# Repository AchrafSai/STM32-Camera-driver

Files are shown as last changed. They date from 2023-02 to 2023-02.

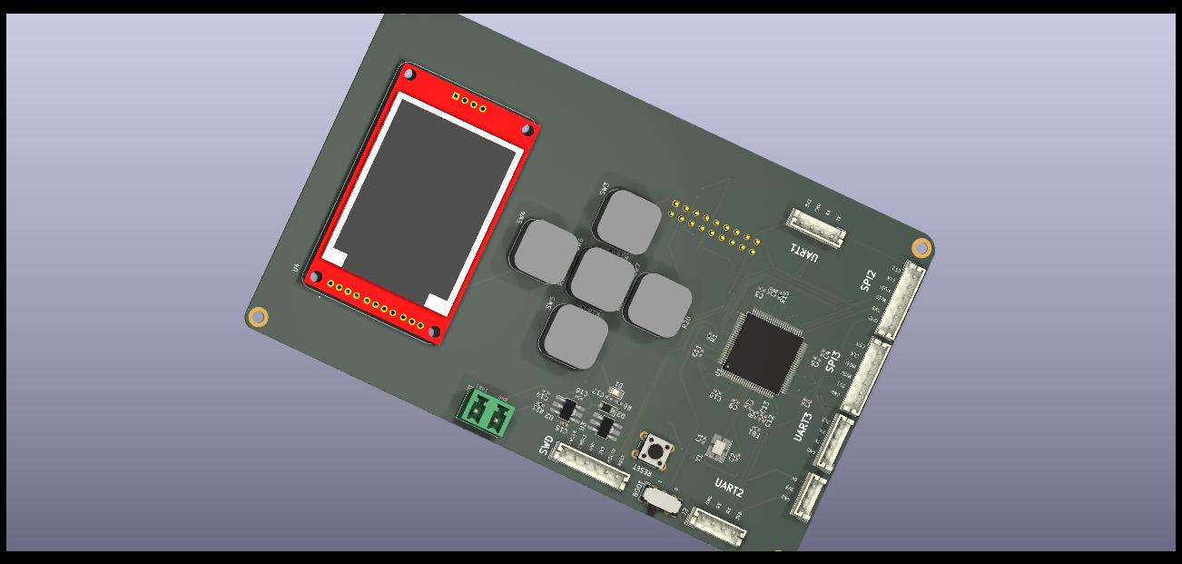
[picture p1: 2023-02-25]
STM32 Camera driver 1.jpg

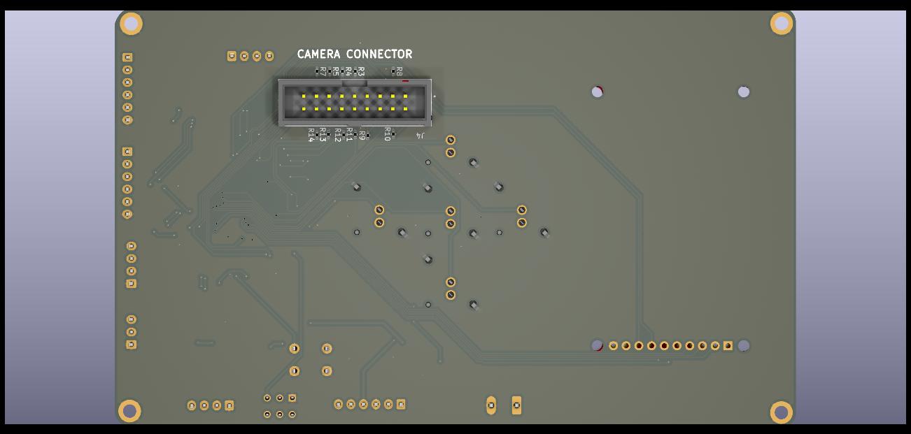
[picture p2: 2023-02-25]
STM32 Camera driver back.jpg

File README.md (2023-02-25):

# STM32 Camera Driver PCB

This project is a custom-designed Printed Circuit Board (PCB) that integrates an STM32H7 microcontroller, a camera module, a display, five buttons, and multiple communication ports.

## Features
The key features of this project are:

STM32H7 Microcontroller: The STM32H7 is a powerful 32-bit microcontroller with a dual-core ARM Cortex-M7 and Cortex-M4 processor, capable of running at up to 480 MHz. It offers a wide range of peripherals and connectivity options, making it ideal for embedded systems applications.

Camera Module: The camera module used in this project is a high-resolution OV5640 sensor that captures 5-megapixel still images and 720p video at 60 frames per second.

Display: The display used in this project is a 1.8-inch TFT LCD screen with a resolution of 320x240 pixels. It provides a clear and bright display for viewing images and video captured by the camera.

Five Buttons: The board includes five buttons for user input, allowing users to control the camera and interact with the user interface displayed on the screen.

Communication Ports: The board includes multiple communication ports, including USB, UART, SPI, and I2C, providing flexibility for communicating with other devices and systems.

## Repository Contents
This repository contains the design files for the PCB, including the schematic, PCB layout, and bill of materials. The KiCad project files are provided, as well as PDFs of the schematic and PCB layout for easy viewing.

## Getting Started
To use this PCB, you will need to assemble and program it. The bill of materials provides a list of components needed, and the KiCad project files can be used to generate the Gerber files needed to manufacture the PCB.

Once the PCB is assembled, you can use the provided example code to get started. The code includes basic functionality for capturing images and video, displaying them on the screen, and interacting with the user through the buttons.

## License
This project is released under the MIT License, meaning that you are free to use, modify, and distribute the code and design files for both personal and commercial use. However, please note that the camera module used in this project may be subject to additional licensing restrictions.

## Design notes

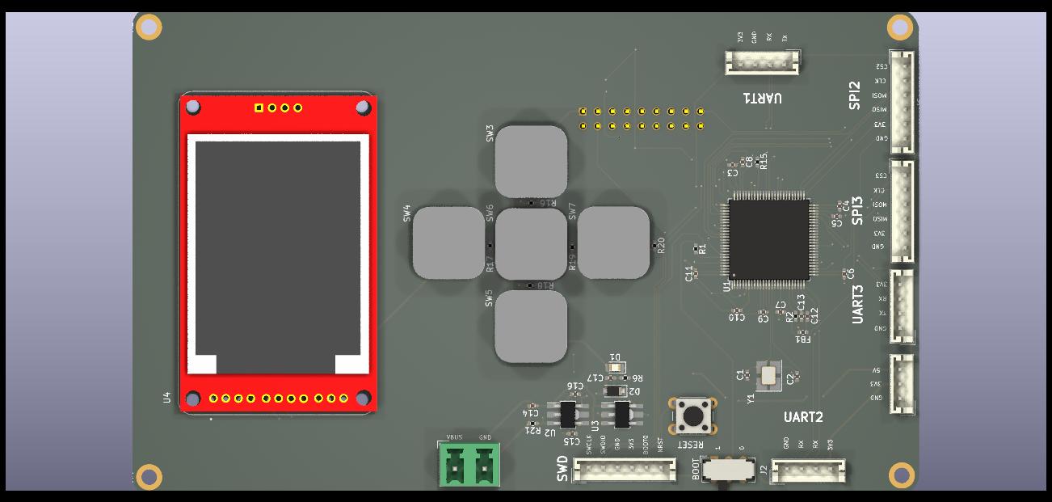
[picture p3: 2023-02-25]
STM32 Camera driver.jpg

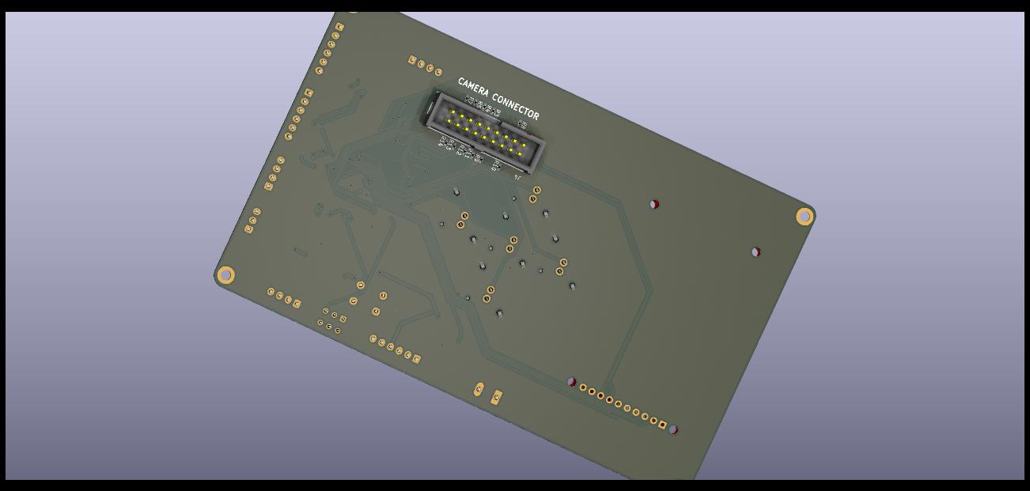
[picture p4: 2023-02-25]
STM32 Camera driver back 1.jpg

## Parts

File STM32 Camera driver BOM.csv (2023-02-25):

Source: | /home/achraf/Documents/KiCad/STM32 Camera driver/STM32 Camera driver.kicad_sch
Date: | 02,15,2023
Tool: | Eeschema 6.0.10-86aedd382b~118~ubuntu20.04.1
Generator: | /usr/share/kicad/plugins/bom_csv_grouped_by_value_with_fp.py
Component Count: | 66
Ref | Qnty | Value | Cmp name | Footprint | Description | Vendor
C1, C2, | 2 | 18p | C | Capacitor_SMD:C_0402_1005Metric_Pad0.74x0.62mm_HandSolder | Unpolarized capacitor
C3, C4, C6, C7, C9, C10, C11, C12, | 8 | 100n | C | Capacitor_SMD:C_0402_1005Metric_Pad0.74x0.62mm_HandSolder | Unpolarized capacitor
C5, C8, | 2 | 2.2u | C | Capacitor_SMD:C_0402_1005Metric_Pad0.74x0.62mm_HandSolder | Unpolarized capacitor
C13, | 1 | 1u | C | Capacitor_SMD:C_0402_1005Metric_Pad0.74x0.62mm_HandSolder | Unpolarized capacitor
C14, C15, C16, C17, | 4 | 3.3u | C | Capacitor_SMD:C_0402_1005Metric_Pad0.74x0.62mm_HandSolder | Unpolarized capacitor
D1, | 1 | LED | LED | LED_SMD:LED_0805_2012Metric_Pad1.15x1.40mm_HandSolder | Light emitting diode
D2, | 1 | DIODE | DIODE | Diode_SMD:D_SOD-123F |  | https://www.lcsc.com/product-detail/Switching-span-style-background-color-ff0-Diode-span_Shanghai-Prisemi-Elec-PSBD1DF40V1H_C110730.html
FB1, | 1 | 600Ω@100MHz | FerriteBead | Inductor_SMD:L_0402_1005Metric_Pad0.77x0.64mm_HandSolder | Ferrite bead | https://www.lcsc.com/product-detail/Ferrite-Beads_Murata-Electronics-BLM15AG601SN1D_C76884.html
H1, H2, H3, H4, | 4 | MountingHole_Pad | MountingHole_Pad | MountingHole:MountingHole_2.7mm_M2.5_ISO14580_Pad | Mounting Hole with connection
J2, J3, | 2 | UART connector | Conn_01x04_Male | Connector_JST:JST_EH_B4B-EH-A_1x04_P2.50mm_Vertical | Generic connector, single row, 01x04, script generated (kicad-library-utils/schlib/autogen/connector/)
J4, | 1 | TST-109-01-G-D | TST-109-01-G-D | Library:SAMTEC_TST-109-01-G-D
J5, | 1 | Conn_01x03_Male | Conn_01x03_Male | Connector_JST:JST_EH_B3B-EH-A_1x03_P2.50mm_Vertical | Generic connector, single row, 01x03, script generated (kicad-library-utils/schlib/autogen/connector/)
J6, J9, J10, | 3 | Conn_01x06_Male | Conn_01x06_Male | Connector_JST:JST_EH_B6B-EH-A_1x06_P2.50mm_Vertical | Generic connector, single row, 01x06, script generated (kicad-library-utils/schlib/autogen/connector/)
J7, | 1 | Voltage input max 10V | Conn_01x02_Male | Connector_Phoenix_MC_HighVoltage:PhoenixContact_MCV_1,5_2-G-5.08_1x02_P5.08mm_Vertical | Generic connector, single row, 01x02, script generated (kicad-library-utils/schlib/autogen/connector/)
J11, | 1 | UART communication for camera | Conn_01x04_Male | Connector_JST:JST_EH_B4B-EH-A_1x04_P2.50mm_Vertical | Generic connector, single row, 01x04, script generated (kicad-library-utils/schlib/autogen/connector/)
R1, R8, R10, R16, R17, R18, R19, R20, R21, | 9 | 10k | R | Resistor_SMD:R_0402_1005Metric_Pad0.72x0.64mm_HandSolder | Resistor
R2, | 1 | 47R | R | Resistor_SMD:R_0402_1005Metric_Pad0.72x0.64mm_HandSolder | Resistor
R3, R4, R5, R7, R11, R12, R13, R14, | 8 | 22R | R_Small | Resistor_SMD:R_0402_1005Metric_Pad0.72x0.64mm_HandSolder | Resistor, small symbol
R6, | 1 | 1.5k | R | Resistor_SMD:R_0402_1005Metric_Pad0.72x0.64mm_HandSolder | Resistor
R9, R15, | 2 | 47k | R | Resistor_SMD:R_0402_1005Metric_Pad0.72x0.64mm_HandSolder | Resistor
SW1, | 1 | SW_DPDT_x2 | SW_DPDT_x2 | Button_Switch_THT:SW_CuK_JS202011AQN_DPDT_Angled | Switch, dual pole double throw, separate symbols
SW2, | 1 | SW_Push | SW_Push | Button_Switch_THT:SW_PUSH_6mm | Push button switch, generic, two pins
SW3, SW4, SW5, SW6, SW7, | 5 | SW_Push | SW_Push | Library:SW_PB300STQ_copy | Push button switch, generic, two pins | https://www.e-switch.com/product-catalog/pb300-series-long-travel-pushbutton-switch
U1, | 1 | STM32H743VITx | STM32H743VITx | Package_QFP:LQFP-100_14x14mm_P0.5mm | ARM Cortex-M7 MCU, 2048KB flash, 864KB RAM, 400MHz, 1.7-3.6V, 82 GPIO, LQFP-100
U2, | 1 | S-1133B50-U5T1x | S-1133_Series_1 | Library:SOT-89-5_Handsoldering
U3, | 1 | S-1133B33-U5T1x | S-1133_Series_1 | Library:SOT-89-5_Handsoldering
U4, | 1 | 358 | 358 | Library:MODULE_358
Y1, | 1 | 25Mhz | Crystal_GND24 | Crystal:Crystal_SMD_3225-4Pin_3.2x2.5mm_HandSoldering | Four pin crystal, GND on pins 2 and 4 | https://www.lcsc.com/product-detail/Oscillators_TAITIEN-Elec-OXETGLJANF-25MHZ_C295525.html

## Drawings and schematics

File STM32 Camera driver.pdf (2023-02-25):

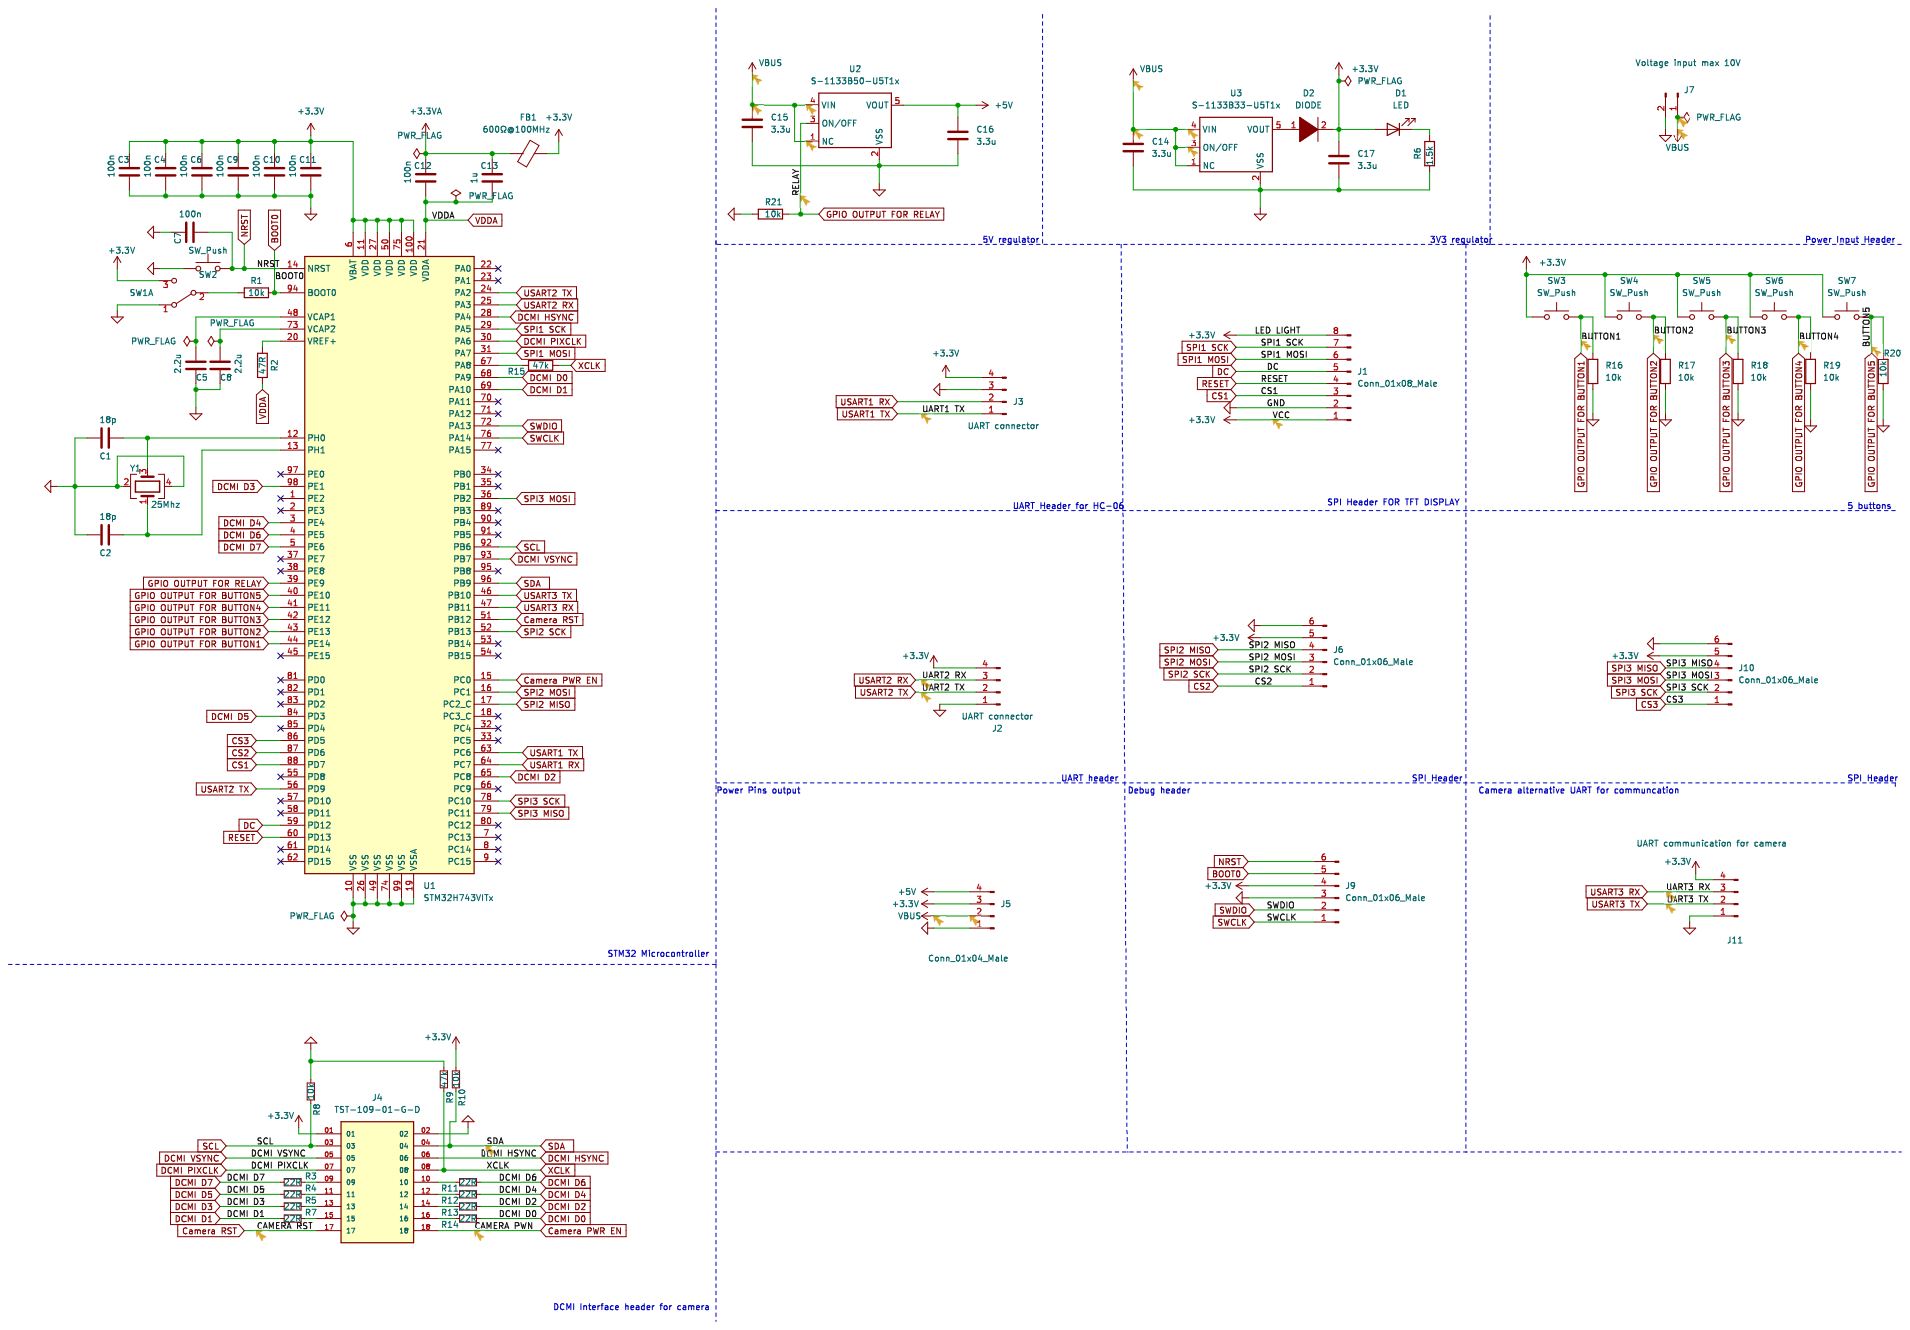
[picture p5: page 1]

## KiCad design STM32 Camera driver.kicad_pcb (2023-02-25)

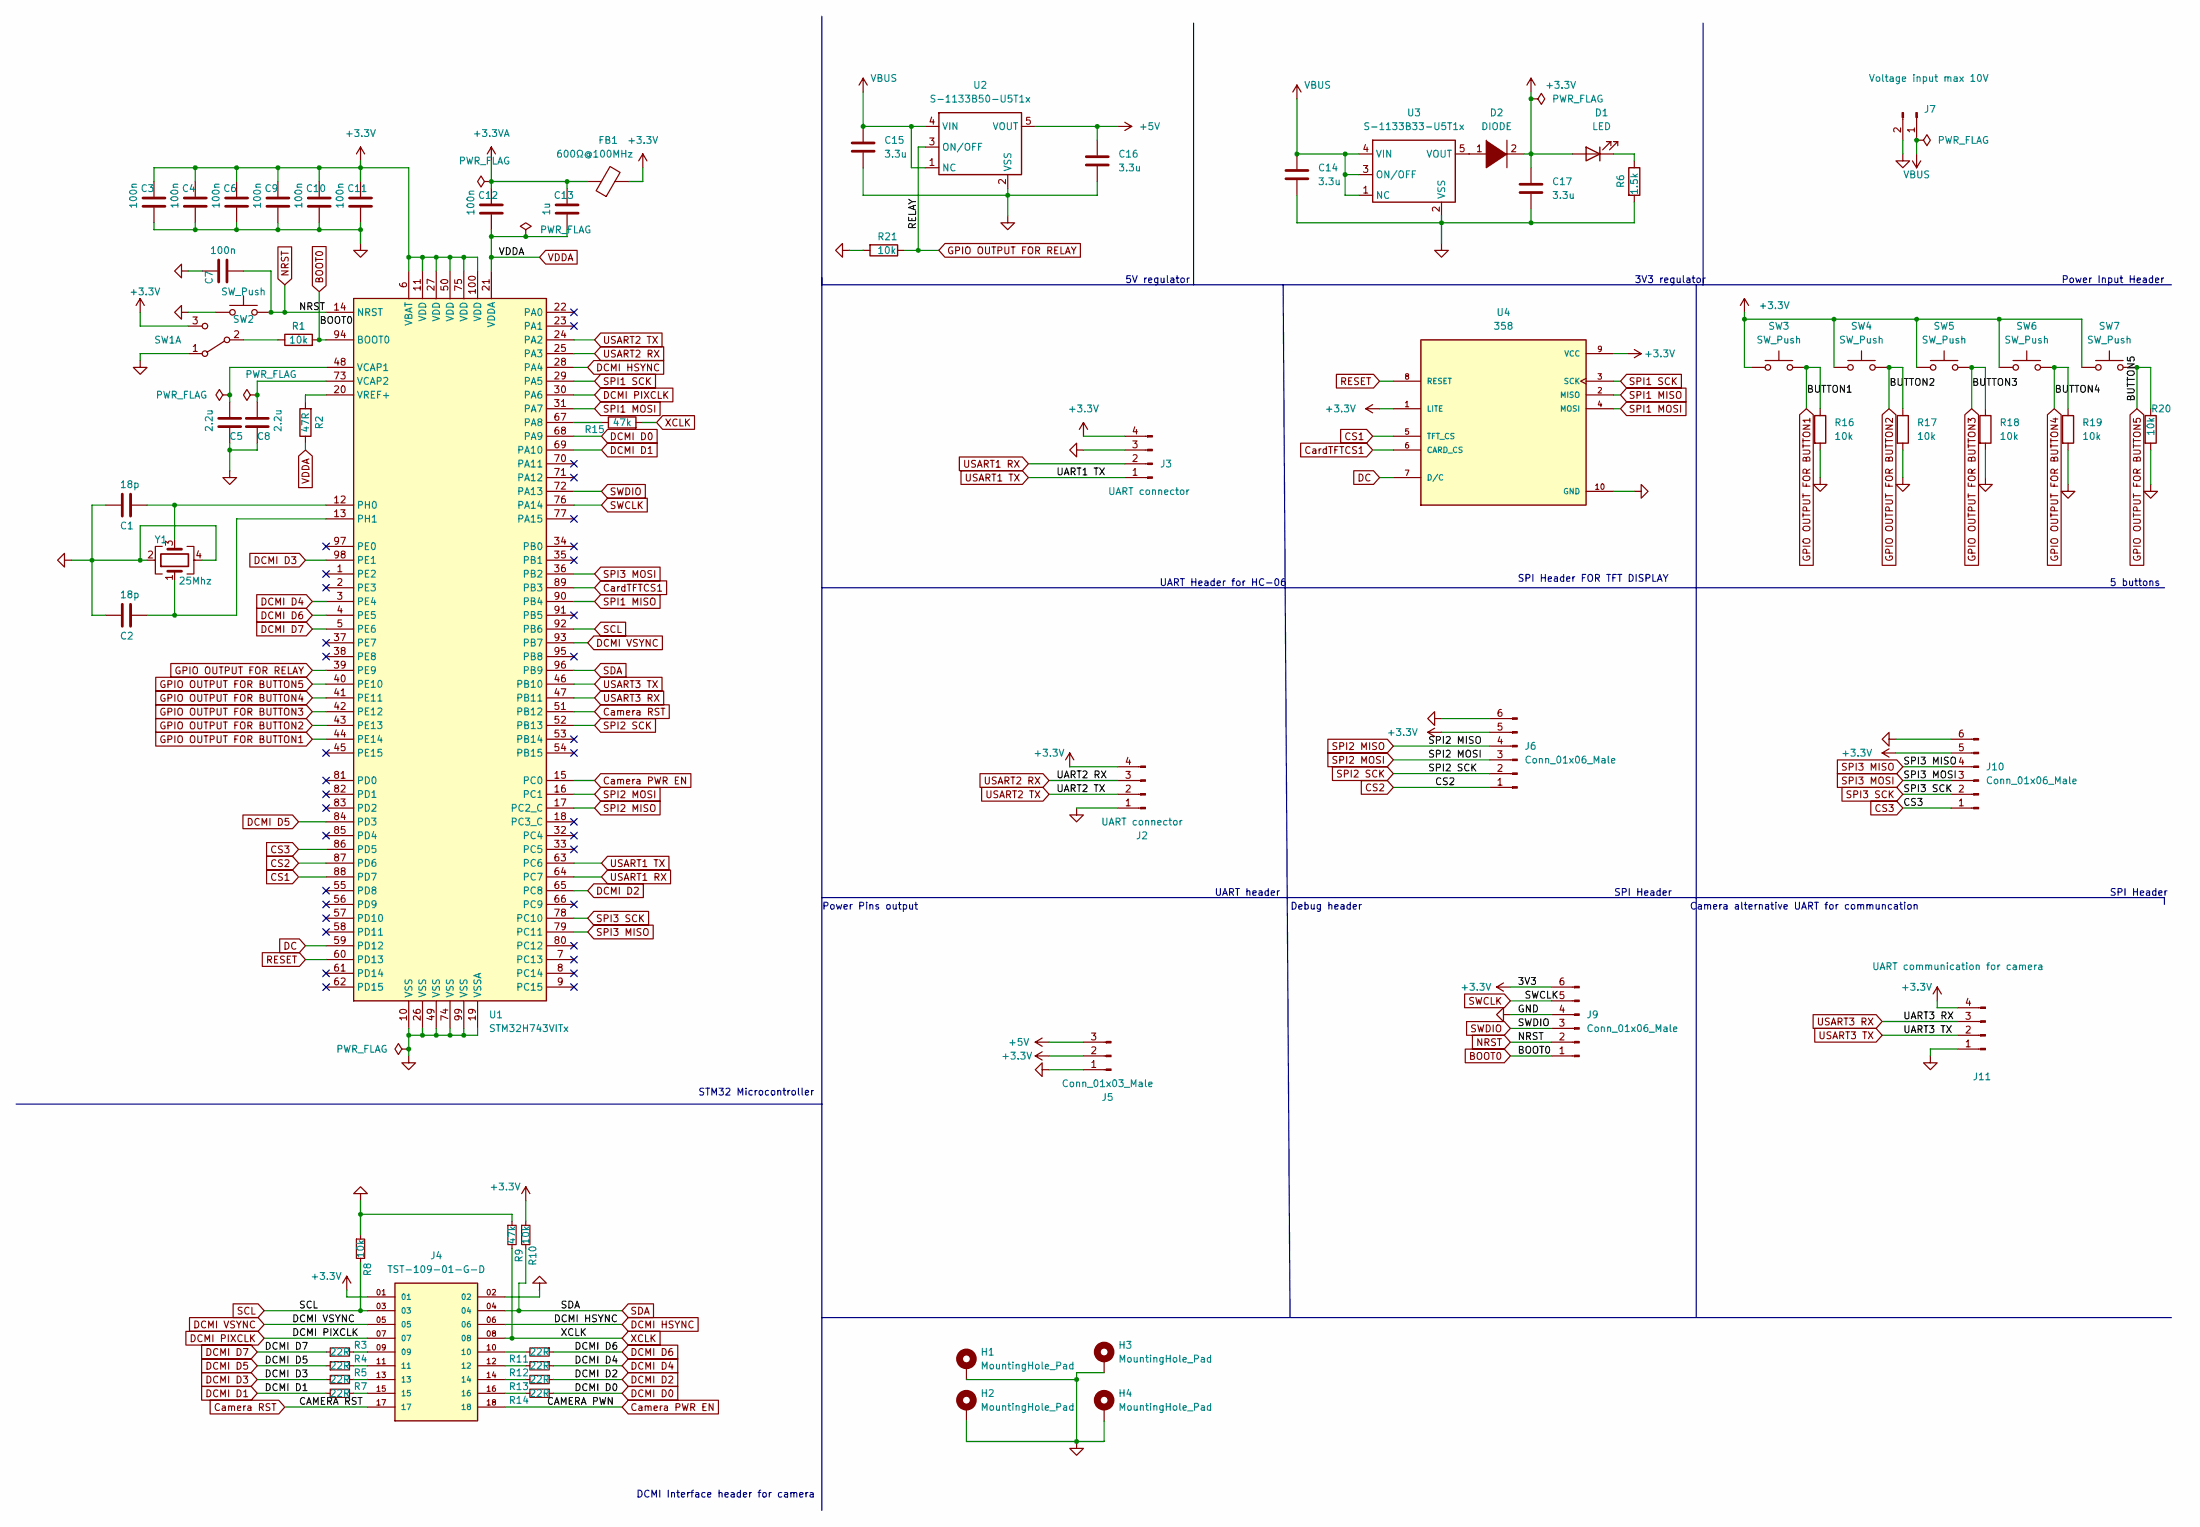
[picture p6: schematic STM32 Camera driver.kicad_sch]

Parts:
C1, C2: 18p; C_0402_1005Metric_Pad0.74x0.62mm_HandSolder
C3, C4, C6, C7, C9, C10, C11, C12: 100n; C_0402_1005Metric_Pad0.74x0.62mm_HandSolder
C5, C8: 2.2u; C_0402_1005Metric_Pad0.74x0.62mm_HandSolder
C13: 1u; C_0402_1005Metric_Pad0.74x0.62mm_HandSolder
C14, C15, C16, C17: 3.3u; C_0402_1005Metric_Pad0.74x0.62mm_HandSolder
D1: LED; LED_0805_2012Metric_Pad1.15x1.40mm_HandSolder
D2: DIODE; D_SOD-123F
FB1: 600Ω@100MHz; L_0402_1005Metric_Pad0.77x0.64mm_HandSolder
H1, H2, H3, H4: MountingHole_Pad; MountingHole_2.7mm_M2.5_ISO14580_Pad
J2, J3: UART connector; JST_EH_B4B-EH-A_1x04_P2.50mm_Vertical
J4: TST-109-01-G-D; SAMTEC_TST-109-01-G-D; PARTREV R
J5: Conn_01x03_Male; JST_EH_B3B-EH-A_1x03_P2.50mm_Vertical
J6, J9, J10: Conn_01x06_Male; JST_EH_B6B-EH-A_1x06_P2.50mm_Vertical
J7: Voltage input max 10V; PhoenixContact_MCV_1,5_2-G-5.08_1x02_P5.08mm_Vertical
J11: UART communication for camera; JST_EH_B4B-EH-A_1x04_P2.50mm_Vertical
R1, R8, R10, R16, R17, R18, R19, R20, R21: 10k; R_0402_1005Metric_Pad0.72x0.64mm_HandSolder
R2: 47R; R_0402_1005Metric_Pad0.72x0.64mm_HandSolder
R3, R4, R5, R7, R11, R12, R13, R14: 22R; R_0402_1005Metric_Pad0.72x0.64mm_HandSolder
R6: 1.5k; R_0402_1005Metric_Pad0.72x0.64mm_HandSolder
R9, R15: 47k; R_0402_1005Metric_Pad0.72x0.64mm_HandSolder
SW1: SW_DPDT_x2; SW_CuK_JS202011AQN_DPDT_Angled
SW2: SW_Push; SW_PUSH_6mm
SW3, SW4, SW5, SW6, SW7: SW_Push; SW_PB300STQ_copy
U1: STM32H743VITx; LQFP-100_14x14mm_P0.5mm
U2: S-1133B50-U5T1x; SOT-89-5_Handsoldering
U3: S-1133B33-U5T1x; SOT-89-5_Handsoldering
U4: 358; MODULE_358; PARTREV 2021-12-09
Y1: 25Mhz; Crystal_SMD_3225-4Pin_3.2x2.5mm_HandSoldering

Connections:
+3.3V: C3.1, C4.1, C6.1, C9.1, C10.1, C11.1, C17.1, D1.2 (A), D2.2 (A), FB1.2, J2.4, J3.4, J4.01, J5.2, J6.5, J9.6, J10.5, J11.4, R10.1, SW1.3 (C), SW3.1, SW4.1, SW5.1, SW6.1, SW7.1, U1.6 (VBAT), U1.11 (VDD), U1.27 (VDD), U1.50 (VDD), U1.75 (VDD), U1.100 (VDD), U4.1 (LITE), U4.9 (VCC); also elsewhere on the board
+3.3VA: C12.1, C13.1, FB1.1
+5V: C16.1, J5.3, U2.5 (VOUT)
BOOT0: J9.1, R1.2, U1.94 (BOOT0)
CS1: U1.88 (PD7), U4.5 (TFT_CS)
CS2: J6.1, U1.87 (PD6)
CS3: J10.1, U1.86 (PD5)
Camera PWR EN: J4.18, U1.15 (PC0)
Camera RST: J4.17, U1.51 (PB12)
CardTFTCS1: U1.89 (PB3), U4.6 (CARD_CS)
DC: U1.59 (PD12), U4.7 (D/C)
DCMI D0: R14.1, U1.68 (PA9)
DCMI D1: R7.1, U1.69 (PA10)
DCMI D2: R13.1, U1.65 (PC8)
DCMI D3: R5.1, U1.98 (PE1)
DCMI D4: R12.1, U1.3 (PE4)
DCMI D5: R4.1, U1.84 (PD3)
DCMI D6: R11.1, U1.4 (PE5)
DCMI D7: R3.1, U1.5 (PE6)
DCMI HSYNC: J4.06, U1.28 (PA4)
DCMI PIXCLK: J4.07, U1.30 (PA6)
DCMI VSYNC: J4.05, U1.93 (PB7)
GND: C1.2, C2.2, C3.2, C4.2, C5.1, C6.2, C7.1, C8.1, C9.2, C10.2, C11.2, C14.1, C15.1, C16.2, C17.2, H1.1, H2.1, H3.1, H4.1, J2.1, J3.3, J4.02, J5.1, J6.6, J7.2, J9.4, J10.6, J11.1, R6.2, R8.1, R9.1, R16.2, R17.2, R18.2, R19.2, R20.2, R21.2, SW1.1 (A), SW2.1, U1.10 (VSS), U1.19 (VSSA), U1.26 (VSS), U1.49 (VSS), U1.74 (VSS), U1.99 (VSS), U2.2 (VSS), U3.2 (VSS), U4.10 (GND), Y1.2, Y1.4; also elsewhere on the board
GPIO OUTPUT FOR BUTTON1: R16.1, SW3.2, U1.44 (PE14)
GPIO OUTPUT FOR BUTTON2: R17.1, SW4.2, U1.43 (PE13)
GPIO OUTPUT FOR BUTTON3: R18.1, SW5.2, U1.42 (PE12)
GPIO OUTPUT FOR BUTTON4: R19.1, SW6.2, U1.41 (PE11)
GPIO OUTPUT FOR BUTTON5: R20.1, SW7.2, U1.40 (PE10)
GPIO OUTPUT FOR RELAY: R21.1, U1.39 (PE9), U2.3 (ON/OFF)
NRST: C7.2, J9.2, SW2.2, U1.14 (NRST); also elsewhere on the board
unnamed: C1.1, U1.12 (PH0), Y1.3
unnamed: C2.1, U1.13 (PH1), Y1.1
unnamed: C5.2, U1.48 (VCAP1)
unnamed: C8.2, U1.73 (VCAP2)
unnamed: D1.1 (K), R6.1
unnamed: D2.1 (K), U3.5 (VOUT)
unnamed: J4.09, R3.2
unnamed: J4.10, R11.2
unnamed: J4.11, R4.2
unnamed: J4.12, R12.2
unnamed: J4.13, R5.2
unnamed: J4.14, R13.2
unnamed: J4.15, R7.2
unnamed: J4.16, R14.2
unnamed 44: R1.1, SW1.2 (B); also elsewhere on the board
unnamed: R2.2, U1.20 (VREF+)
unnamed: R15.1, U1.67 (PA8)
RESET: U1.60 (PD13), U4.8 (RESET)
SCL: J4.03, R8.2, U1.92 (PB6)
SDA: J4.04, R10.2, U1.96 (PB9)
SPI1 MISO: U1.90 (PB4), U4.2 (MISO)
SPI1 MOSI: U1.31 (PA7), U4.4 (MOSI)
SPI1 SCK: U1.29 (PA5), U4.3 (SCK)
SPI2 MISO: J6.4, U1.17 (PC2_C)
SPI2 MOSI: J6.3, U1.16 (PC1)
SPI2 SCK: J6.2, U1.52 (PB13)
SPI3 MISO: J10.4, U1.79 (PC11)
SPI3 MOSI: J10.3, U1.36 (PB2)
SPI3 SCK: J10.2, U1.78 (PC10)
SWCLK: J9.5, U1.76 (PA14)
SWDIO: J9.3, U1.72 (PA13)
USART1 RX: J3.2, U1.64 (PC7)
USART1 TX: J3.1, U1.63 (PC6)
USART2 RX: J2.3, U1.25 (PA3)
USART2 TX: J2.2, U1.24 (PA2)
USART3 RX: J11.3, U1.47 (PB11)
USART3 TX: J11.2, U1.46 (PB10)
VBUS: C14.2, C15.2, J7.1, U2.1 (NC), U2.4 (VIN), U3.1 (NC), U3.3 (ON/OFF), U3.4 (VIN)
VDDA: C12.2, C13.2, R2.1, U1.21 (VDDA)
XCLK: J4.08, R9.2, R15.2

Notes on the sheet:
Debug header
Power Pins output
UART header
5V regulator
3V3 regulator
UART Header for HC-06
Camera alternative UART for communcation
5 buttons
STM32 Microcontroller
SPI Header
SPI Header FOR TFT DISPLAY
Power Input Header
DCMI Interface header for camera

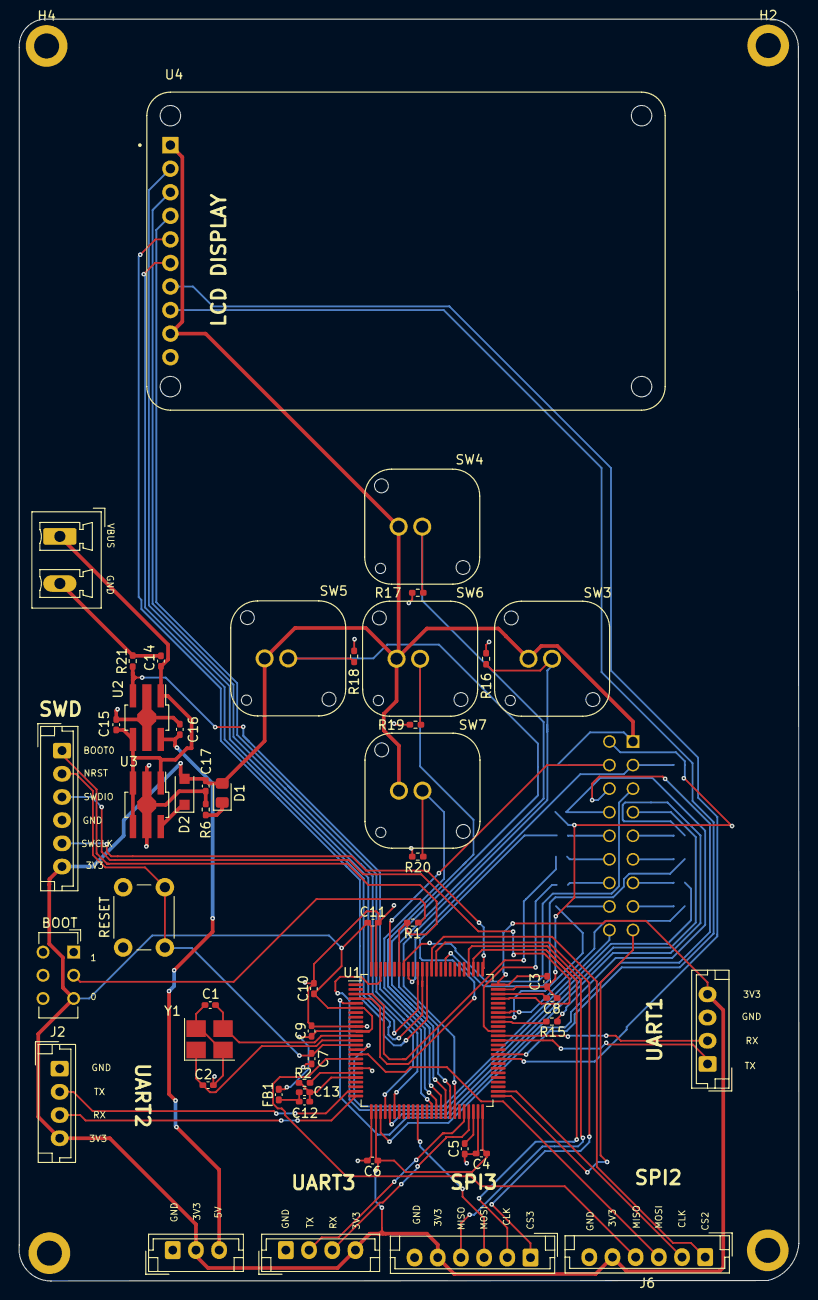
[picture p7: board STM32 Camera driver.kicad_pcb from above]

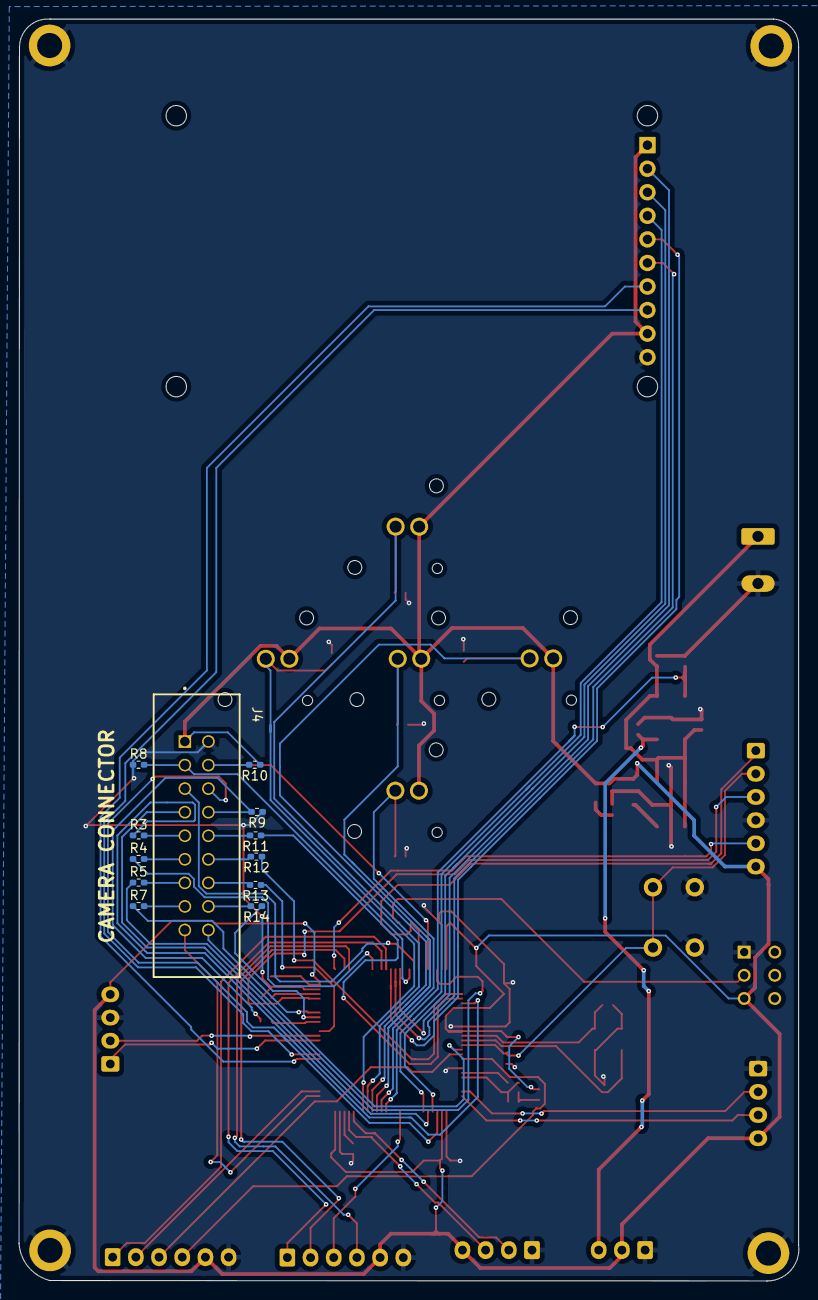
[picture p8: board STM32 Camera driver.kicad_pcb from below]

Board: 2 copper layers, 84.1 x 136.1 mm, 66 parts (12 on the bottom side), 70 nets.

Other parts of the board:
BOOT: SW_DPDT_x2; SW_CuK_JS202011AQN_DPDT_Angled
RESET: SW_Push; SW_PUSH_6mm

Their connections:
+3.3V: BOOT.3 (C); also elsewhere on the board
GND: BOOT.1 (A), RESET.1; also elsewhere on the board
NRST: RESET.2; also elsewhere on the board
unnamed 44: BOOT.2 (B); also elsewhere on the board
